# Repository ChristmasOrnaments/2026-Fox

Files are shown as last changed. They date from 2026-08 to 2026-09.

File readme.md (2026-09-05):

Christmas ornament number 14...

***

The detailed explanation of the original Snowman ornament is [here](https://github.com/timtilities/ChristmasOrnaments--2013-Snowman).

This ornament has been redesigned around the newer Attiny412. The schematic and PCB have been updated to use UPDI programming and the new pinout of the Attiny412. Since these use UPDI, you will need a programmer. I am currently using a [converted Arduino Nano](https://daumemo.com/diy-updi-usb-programmer-which-can-be-made-with-cheap-hardware/) as a [jtag2updi](https://github.com/ElTangas/jtag2updi) programmer. 

Animated
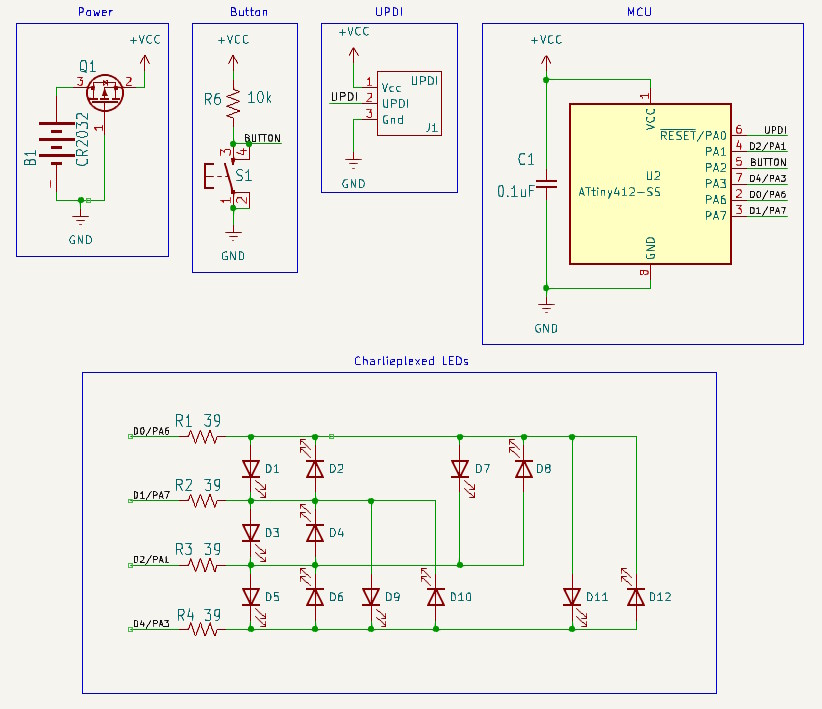
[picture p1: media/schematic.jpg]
schematic

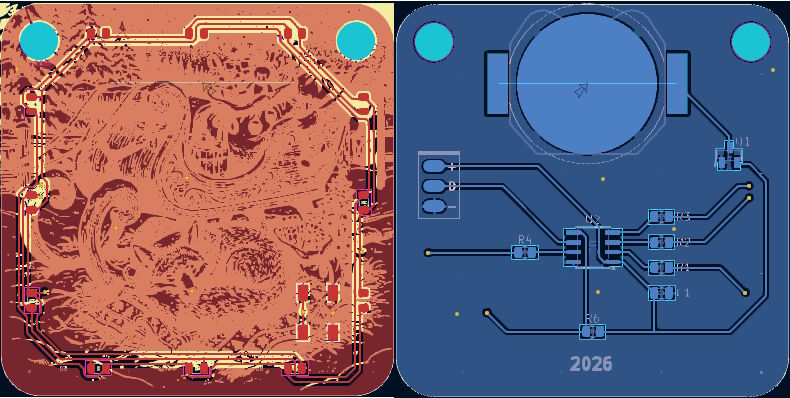
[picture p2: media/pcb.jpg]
PCB

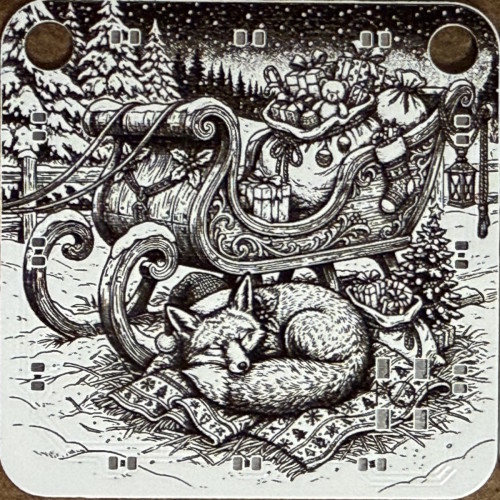
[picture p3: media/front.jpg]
Front


### Compiling with Arduino IDE

* Install [megaTinyCore](https://github.com/SpenceKonde/megaTinyCore) using the boards manager
* Select **Attiny412/402/212/202** from the boards list
* Set the *Clock source* to **4MHz (internal)**
* Set *B.O.D Mode* to **Disabled**
* Set *B.O.D. voltage level* to **1.8v**
* Select the **Attiny412** chip
* Select **Burn Bootloader** to write the fuses
* Compile and upload the program to the MCU

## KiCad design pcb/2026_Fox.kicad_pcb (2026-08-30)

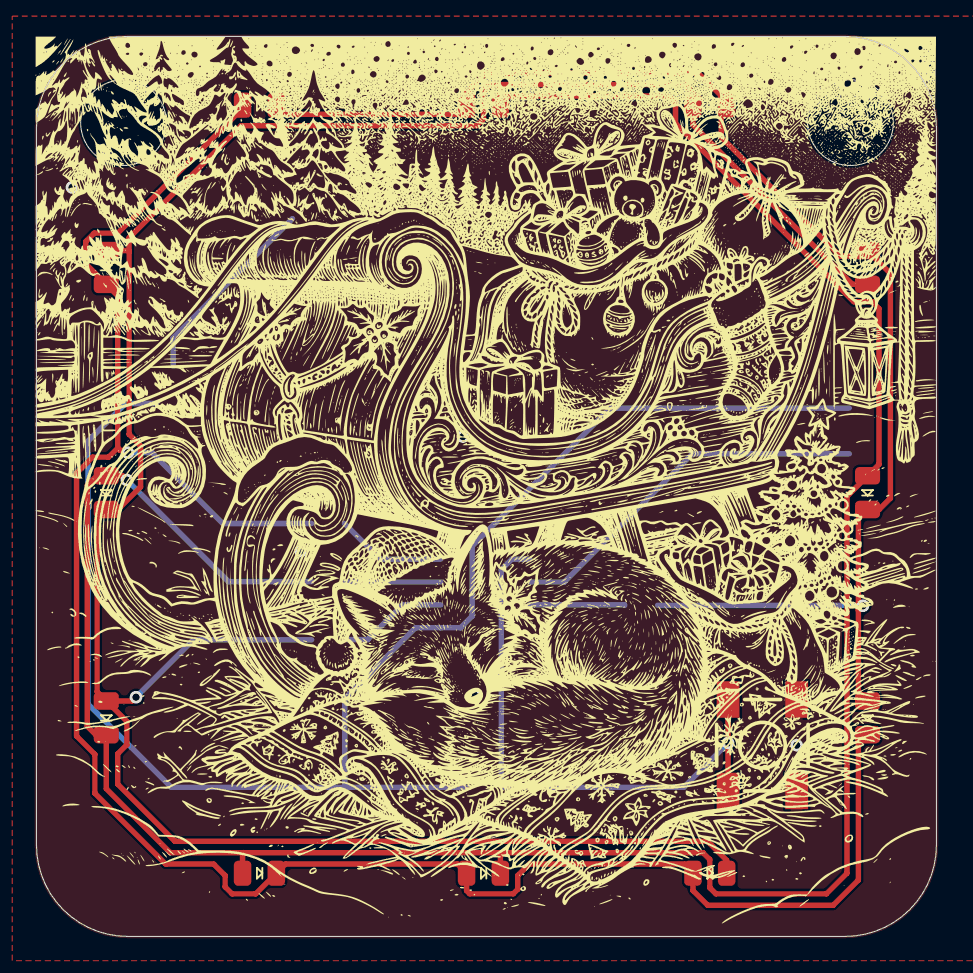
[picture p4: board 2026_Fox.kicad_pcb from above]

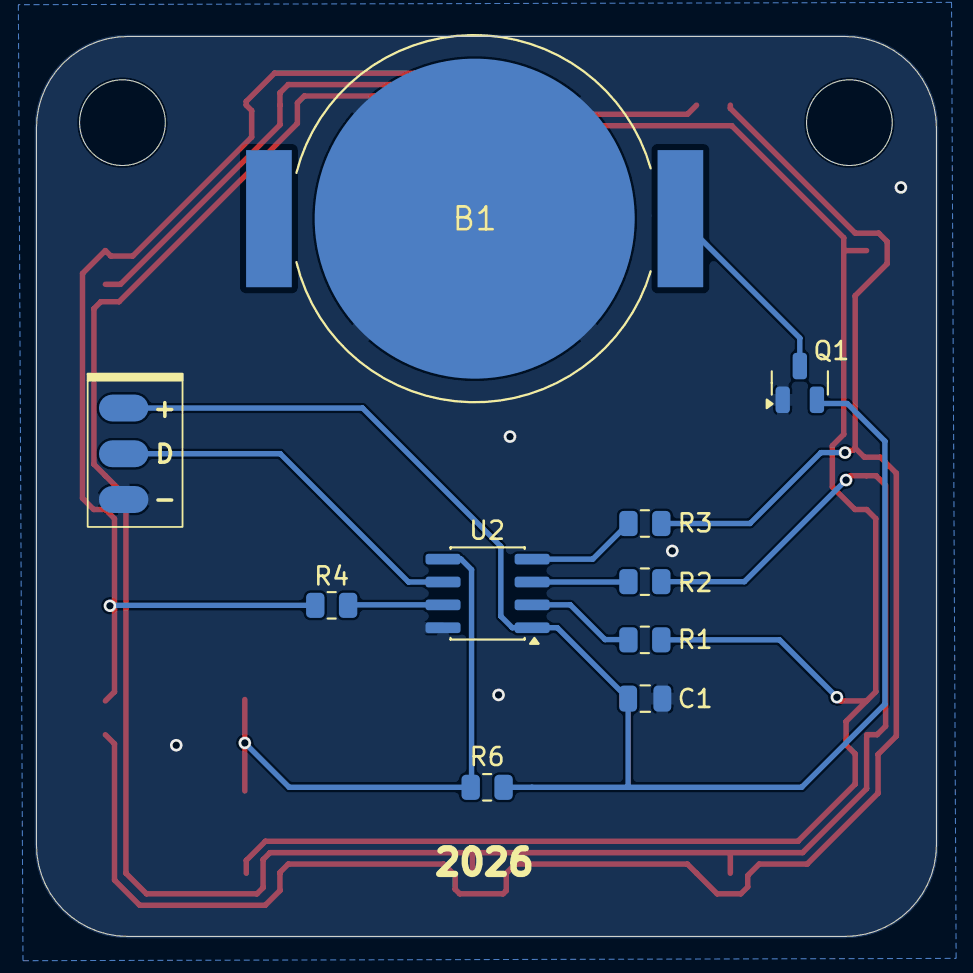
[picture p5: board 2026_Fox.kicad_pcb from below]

Board: 2 copper layers, 50.0 x 50.0 mm, 25 parts (10 on the bottom side), 13 nets.

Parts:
B1: CR2032; BAT-HLD-001
C1: 0.1uF; C_0805_2012Metric
D1, D5, D8, D12: RED; LED_0805_2012Metric_Red
D2, D4, D9, D10: WHITE; LED_0805_2012Metric_White
D3, D6, D7, D11: GREEN; LED_0805_2012Metric_Green
J1: UPDI; AVR_UPDI_3_SMD
Q1: DMG2305UX; SOT-23
R1, R2, R3, R4: 39; R_0805_2012Metric
R6: 10k; R_0805_2012Metric
S1: TACTILE_SWITCH_SMD
TH*: NPTH
TH*#2: NPTH
U2: ATtiny412-SS; SOIC-8_3.9x4.9mm_P1.27mm

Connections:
+VCC: C1.1, J1.1 (Vcc), Q1.2 (S), R6.1, U2.1 (VCC)
/BUTTON: R6.2, S1.3, S1.4, U2.5 (PA2)
/D0/PA6: R1.2, U2.2 (PA6)
/D1/PA7: R2.2, U2.3 (PA7)
/D2/PA1: R3.2, U2.4 (PA1)
/D4/PA3: R4.2, U2.7 (PA3)
/UPDI: J1.2 (UPDI), U2.6 (~RESET/PA0)
GND: B1.-, C1.2, J1.3 (Gnd), Q1.1 (G), S1.1, S1.2, U2.8 (GND)
unnamed: D1.2 (A), D2.1 (K), D7.2 (A), D8.1 (K), D11.2 (A), D12.1 (K), R1.1
unnamed: D1.1 (K), D2.2 (A), D3.2 (A), D4.1 (K), D9.2 (A), D10.1 (K), R2.1
unnamed: D3.1 (K), D4.2 (A), D5.2 (A), D6.1 (K), D7.1 (K), D8.2 (A), R3.1
unnamed: D5.1 (K), D6.2 (A), D9.1 (K), D10.2 (A), D11.1 (K), D12.2 (A), R4.1
unnamed: B1.+@1, B1.+@2, Q1.3 (D)

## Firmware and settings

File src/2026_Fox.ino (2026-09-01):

/*
 * ATTiny412, 4MHz Internal
 *
 * Created: 4/9/2026
 *	Author: Timinator2020
 *  Charlieplexing functions modeled after the code found here:
 *    http://www.instructables.com/id/CharliePlexed-LED-string-for-the-Arduino/step7/Coding-the-Arduino/
 *
 */

/* ATTINY412 / ARDUINO
 *                      ____
 *               VCC  1|*   |8  GND
 *         (D0)  PA6  2|    |7  PA3  (D4)
 *         (D1)  PA7  3|    |6  PA0  (D5)  UPDI
 *    PWM  (D2)  PA1  4|____|5  PA2  (D3)  PWM
 */

#include <avr/sleep.h>

#define DISPLAY_SEQUENCE(seq, speed) displaySequence(seq, sizeof(seq) / sizeof(seq[0]), speed)

constexpr uint8_t ButtonPin = PIN_PA2; // D3 - Pullup on the PCB (disable internal pullups)
constexpr uint8_t LED_COUNT = 12; // Total number of LEDs on the PCB
constexpr uint8_t BlinkDelay = 120; // microseconds the LED will be on, then off. It can affect brightness, but mostly affects speed
constexpr uint8_t SequenceCnt = 8; // Total number of sequences to display

volatile bool TriggerNow = true;

// Arrays to hold pin masks
byte AnodeMask[LED_COUNT];
byte CathodeMask[LED_COUNT];

// LED pin connections => { Anode, Cathode }
//   These are NOT Arduino pin numbers (D1/D2/etc)! They are **PORTA bit positions**
//   These numbers correspond to the # after 'PA' in the pinout diagram above (for MegaTinyCore).
// PA6=6 (D0), PA7=7 (D1), PA1=1 (D2), PA2=2 (D3), PA3=3 (D4), PA0=0 (D5/UPDI)
constexpr uint8_t LEDConnections[LED_COUNT][2] = {  
  { 6 , 7 }, // LED1  (PA6/D0, PA7/D1)
  { 7 , 1 }, // LED3  (PA7/D1, PA1/D2)
  { 1 , 3 }, // LED5  (PA1/D2, PA3/D4)
  { 7 , 6 }, // LED2  (PA7/D1, PA6/D0)
  { 1 , 7 }, // LED4  (PA1/D2, PA7/D1)
  { 3 , 1 }, // LED6  (PA3/D4, PA1/D2)
  { 6 , 1 }, // LED7  (PA6/D0, PA1/D2)
  { 7 , 3 }, // LED9  (PA7/D1, PA3/D4)
  { 1 , 6 }, // LED8  (PA1/D2, PA6/D0)
  { 3 , 7 }, // LED10 (PA3/D4, PA7/D1)
  { 6 , 3 }, // LED11 (PA6/D0, PA3/D4)
  { 3 , 6 }  // LED12 (PA3/D4, PA6/D0)
};

/**************************************************************************/
/**                      LED Sequence Definitions                        **/
/**************************************************************************/
/*
 * LED location in bit array:
 * Bit: 0b [D12] [D11] [D10] [D8] [D9] [D7] [D6] [D4] [D2] [D5] [D3] [D1] 
 * 
 * Example LED sequences:
 * 
 * 0b000000000001, // LED 1
 * 0b000000000010, // LED 3
 * 0b000000000100, // LED 5
 * 0b000000001000, // LED 2
 * 0b000000010000, // LED 4
 * 0b000000100000, // LED 6
 * 0b000001000000, // LED 7
 * 0b000010000000, // LED 9
 * 0b000100000000, // LED 8
 * 0b001000000000, // LED 10
 * 0b010000000000, // LED 11
 * 0b100000000000  // LED 12
 * 
 * Turn on LEDs 3, 8 and 11:
 *   0b010100000010 // 2nd position is D11, 4th position is D8 & 11th position is D3
 */

// NOTE:
// * On modern megaAVR architectures like the ATtiny412 (AVR 0-series), Flash memory is mapped into the unified 16-bit data address space.
// * Flash data can be read directly via regular pointer dereferencing without requiring macros like pgm_read_word().

constexpr uint16_t SeqAllOff[] = { // Turn everything off
  0b000000000000
};

constexpr uint16_t SeqAllOn[] = { // Turn everything on
  0b111111111111
};

constexpr uint16_t SeqRaceCW[] = { // 3 LEDs Race Clockwise
  0b000000000100, 0b001000000100, 0b011000000100, 0b111000000000, 
  0b110010000000, 0b100010100000, 0b000110100000, 0b000100110000, 
  0b000100010010, 0b000000010011, 0b000000001011, 0b000001001001, 
  0b000001001100, 0b001001000100, 0b011000000100, 0b111000000000, 
  0b110010000000, 0b100010100000, 0b000110100000, 0b000100110000, 
  0b000100010010, 0b000000010011, 0b000000001011, 0b000001001001, 
  0b000001001000, 0b000001000000
};

constexpr uint16_t SeqPlusSpin[] = { // "+" rotation
  0b100100000101, 0b001010011000, 0b010001100010, 0b100100000101,
  0b001010011000, 0b010001100010, 0b100100000101, 0b001010011000,
  0b010001100010, 0b100100000101, 0b001010011000, 0b010001100010
};

constexpr uint16_t SeqOscillate[] = { // 2 LEDs Racing back and forth
  0b000010001000, 0b100001100001, 0b010100000110, 0b001000010000,
  0b010100000110, 0b100001100001
};

constexpr uint16_t SeqKittyCorner[] = { // 2 LEDs race from top-left corner to bottom-right corner and back
  0b000000000100, 0b001001000000, 0b010000001000, 0b100000000001, 
  0b000010000010, 0b000000110000, 0b000100000000, 0b000000110000, 
  0b000010000010, 0b100000000001, 0b010000001000, 0b001001000000
};

constexpr uint16_t SeqRaceCCW[] = { // 3 LED Race Counter-Clockwise
  0b000001000000, 0b000001001000, 0b000001001001, 0b000000001011, 
  0b000000010011, 0b000100010010, 0b000100110000, 0b000110100000, 
  0b100010100000, 0b110010000000, 0b111000000000, 0b011000000100, 
  0b001001000100, 0b000001001100, 0b000001001001, 0b000000001011, 
  0b000000010011, 0b000100010010, 0b000100110000, 0b000110100000, 
  0b100010100000, 0b110010000000, 0b111000000000, 0b011000000100, 
  0b001000000100, 0b000000000100
};

constexpr uint16_t SeqCurtains[] = { // LEDs race from top-center to bottom-center in opposite directions
  0b010000000100, 0b100001000000, 0b000010001000, 0b000000100001,
  0b000100000010, 0b000000010000, 0b000100000010, 0b000000100001,
  0b000010001000, 0b100001000000, 0b010000000100, 0b001000000000
};


/**************************************************************************/
/**                     Charlieplexing functions                         **/
/**************************************************************************/

// Turns on the specified LED
void turnOn(int Led) {
  PORTA.DIRSET = (AnodeMask[Led] | CathodeMask[Led]); // Set both as outputs
  PORTA.OUTSET = AnodeMask[Led]; // Anode HIGH
  PORTA.OUTCLR = CathodeMask[Led]; // Cathode LOW
}

// Turns ALL LEDs off
void allOff() {
  // digitalWrite has to look up each pin mask, each time (not very efficient).
  // This does the same thing without lookups
  uint8_t Mask = (1 << 6) | (1 << 7) | (1 << 1) | (1 << 3);
  PORTA.DIRCLR = Mask;
  PORTA.OUTCLR = Mask;
}

// Loads a sequence from array reference
void displaySequence(const uint16_t* sequence, size_t count, int tranSpeed) {
  for (size_t frame = 0; frame < count; frame++) {
    uint16_t displayData = sequence[frame];

    for (int i = 0; i < tranSpeed; i++) {
      for (int j = 0; j < LED_COUNT; j++) {
        if (bitRead(displayData, j)) {
          turnOn(j);
          delayMicroseconds(BlinkDelay);
        } else {
          delayMicroseconds(BlinkDelay);
        }
        allOff();
      }
    }
  }
}

// Twinkle effect - Turns all LEDs on and randomly shuts LED(s) off for a short duration
void twinkleLEDs(int TranSpeed, int FramesOff, int SeqCount) {
  uint8_t lastIndex = 255;

  for (int frame = 0; frame < SeqCount; frame++) {
    // Select NEW random LED
    uint8_t offIdx;
    do {
      offIdx = random(0, LED_COUNT);
    } while (offIdx == lastIndex);
    lastIndex = offIdx;

    // Display total sequence frame duration (TranSpeed)
    for (int t = 0; t < TranSpeed; t++) {
      bool isOff = (t < FramesOff);

      for (uint8_t j = 0; j < LED_COUNT; j++) {
        // If in Off phase and current LED matches targeted index, turn off
        if (isOff && (j == offIdx)) {
          delayMicroseconds(BlinkDelay);
        } else {
          turnOn(j);
          delayMicroseconds(BlinkDelay);
          allOff();
        }
      }
    }
  }
}

// Get the next random number (Fisher-Yates Shuffle)
int getRndNumber() {
  static int PastRnd = -1;
  static int RndAvailable[8];
  static int RndIdx = SequenceCnt;

  if (RndIdx >= SequenceCnt) { // Reshuffle if exhausted
    for (int i = 0; i < SequenceCnt; i++) { 
      RndAvailable[i] = i + 1;
    }
    
    for (int i = SequenceCnt - 1; i > 0; i--) { // Fisher-Yates Shuffle
      int idx = random(0, i + 1);
      int k = RndAvailable[i];
      RndAvailable[i] = RndAvailable[idx];
      RndAvailable[idx] = k;
    }
    
    // Ensure the first element of the new cycle isn't consecutive to the last element of the previous cycle
    if (abs(RndAvailable[0] - PastRnd) <= 1 && SequenceCnt > 1) {
      int k = RndAvailable[0];
      RndAvailable[0] = RndAvailable[1];
      RndAvailable[1] = k;
    }
    
    RndIdx = 0;
  }

  PastRnd = RndAvailable[RndIdx];
  return RndAvailable[RndIdx++];
}


/**************************************************************************/
/**                      Power Management functions                      **/
/**************************************************************************/

// Button (Execute) ISR
ISR(PORTA_PORT_vect) {
    //PORTA.INTFLAGS = 0xFF; // Clear all Port A flags
    PORTA.INTFLAGS = PORT_INT2_bm; // Clear PA2 interrupt flag
    TriggerNow = true;
}

// RTC ISR
ISR(RTC_CNT_vect) {
    RTC.INTFLAGS = RTC_OVF_bm; // Clear Overflow flag
    TriggerNow = true;
}

// Initialize all needed GPIO
void initGPIO(void) {
    // Disable input buffers on all pins to save power
    PORTA.PIN0CTRL = PORT_ISC_INPUT_DISABLE_gc;
    PORTA.PIN1CTRL = PORT_ISC_INPUT_DISABLE_gc;
    PORTA.PIN2CTRL = PORT_ISC_INPUT_DISABLE_gc;
    PORTA.PIN3CTRL = PORT_ISC_INPUT_DISABLE_gc;
    PORTA.PIN6CTRL = PORT_ISC_INPUT_DISABLE_gc;
    PORTA.PIN7CTRL = PORT_ISC_INPUT_DISABLE_gc;
    // Enable the input buffer for ButtonPin
    *(&PORTA.PIN0CTRL + digitalPinToBitPosition(ButtonPin)) = PORT_ISC_FALLING_gc;
    // If I set ButtonPin to the bit position (2) instead of PIN_PA2, I wouldn't need digitalPinToBitPosition(), but it would be more confusing
}

// Initialize the 32KHz internal ultra low power 32 kHz oscillator 
void initULPOsc(void) {
    // RTC Setup
    while (RTC.STATUS > 0);
    RTC.CLKSEL = RTC_CLKSEL_INT1K_gc; // 1024Hz ULP Osc
    // RTC.PER = Sleep time in seconds
    //RTC.PER = 3; // 3 seconds
    //RTC.PER = 10;  // 10 seconds
    //RTC.PER = 420;  // 7 Minutes
    RTC.PER = 900;  // 15 Minutes
    RTC.INTCTRL = RTC_OVF_bm; // Enable Overflow Interrupt
    
    // Start RTC with 1024 prescaler (RUNSTDBY is required!)
    RTC.CTRLA = RTC_PRESCALER_DIV1024_gc | RTC_RTCEN_bm | RTC_RUNSTDBY_bm;
}


/**************************************************************************/
/**                          Arduino Functions                           **/
/**************************************************************************/

void setup() {
  // Auto-generate LED masks
  for(int i = 0; i < LED_COUNT; i++) {
    AnodeMask[i] = (1 << LEDConnections[i][0]);
    CathodeMask[i] = (1 << LEDConnections[i][1]);
  }
  // initialize things
  initGPIO();
  initULPOsc();
  set_sleep_mode(SLEEP_MODE_STANDBY); // Must use SLEEP_MODE_STANDBY for RTC_CNT to function - otherwise it will not wake from PWR_DOWN
  sei(); // Enable Global Interrupts (for wakeup)
}

void loop() {
  static int SequenceIdx = 0;
  
  if (TriggerNow) {
    // --- MAIN WAKE CODE HERE ---
      
    for (int demos=0; demos<3; demos++) {
      bool Random = true;
      if (Random) {
        SequenceIdx = getRndNumber();
      } else {
        SequenceIdx = (SequenceIdx % SequenceCnt) + 1;
      }
      switch (SequenceIdx) {
        case 1: // Sequence 1 - All LEDs Flash
          for (int loop = 0; loop < 4; loop++) {
            DISPLAY_SEQUENCE(SeqAllOff, 210); delay(50);
            DISPLAY_SEQUENCE(SeqAllOn, 210); delay(150);
          }
          break;

        case 2: // Sequence 2 - 3 LEDs Race Clockwise
          for (int loop=0; loop<2; loop++) { DISPLAY_SEQUENCE(SeqRaceCW, 70); }
          break;
          
        case 3: // Sequence 3 - '+' rotation
        	for (int loop=0; loop<3; loop++) { DISPLAY_SEQUENCE(SeqPlusSpin, 70); }
          break;

        case 4: // Sequence 4 - 2 LEDs Racing back and forth
          for (int loop = 0; loop < 4; loop++) { DISPLAY_SEQUENCE(SeqOscillate, 70); }
          break;

        case 5: // Sequence 5 - Top-left to bottom-right
          for (int loop = 0; loop < 3; loop++) { DISPLAY_SEQUENCE(SeqKittyCorner, 70); }
          break;

        case 6: // Sequence 6 - Counter-Clockwise
          for (int loop = 0; loop < 2; loop++) { DISPLAY_SEQUENCE(SeqRaceCCW, 70); }
          break;

        case 7: // Sequence 7 - Opposite directions
          for (int loop = 0; loop < 3; loop++) { DISPLAY_SEQUENCE(SeqCurtains, 70); }
          break;

        case 8: // Twinkle sequence
          twinkleLEDs(70, 75, 40);
          break;
      }
    }

    // --- END WAKE CODE ---

    // Reset timer so we get a full cycle after a button press
    while (RTC.STATUS > 0); // Wait for RTC to be ready
    RTC.CNT = 0; // Reset counter
    while (RTC.STATUS > 0); // Wait for update to complete

    // reset for next wake cycle
    TriggerNow = false;
  }

  // Go to sleep
  if (!TriggerNow) { // Prevent sleep race condition
    // set_sleep_mode(SLEEP_MODE_STANDBY); // Set Sleep Mode (Must use SLEEP_MODE_STANDBY for RTC_CNT to function - otherwise it will not wake from PWR_DOWN)
    sleep_enable();
    sleep_cpu(); // Go to sleep

    // ... (: SLEEPING :) ...

    // Wake back up
    // wakeUp();
    sleep_disable();
    initGPIO(); // initialize GPIO
  }
}
